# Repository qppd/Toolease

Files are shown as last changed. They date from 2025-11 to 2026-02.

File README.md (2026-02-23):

# ToolEase

**A modern, open-source RFID-based tool leasing and inventory management system for educational, industrial, and makerspace environments.**

---

## Table of Contents

- [Overview](#overview)
- [Key Features](#key-features)
- [System Architecture](#system-architecture)
- [Hardware Requirements](#hardware-requirements)
- [Wiring Diagram](#wiring-diagram)
- [Software Dependencies](#software-dependencies)
- [Installation & Setup](#installation--setup)
- [Configuration](#configuration)
- [Operation Guide](#operation-guide)
- [API & Communication](#api--communication)
- [Testing & Validation](#testing--validation)
- [Troubleshooting](#troubleshooting)
- [Project Structure](#project-structure)
- [Future Enhancements](#future-enhancements)
- [Contributing](#contributing)
- [Support & Contact](#support--contact)
- [License](#license)

---

## Overview

ToolEase is a complete IoT solution for managing tool lending, inventory, and asset tracking. It combines a robust Flutter mobile app with an ESP32-based RFID hardware interface, enabling real-time, per-unit tracking of tools and equipment. Designed for schools, universities, workshops, and industrial settings, ToolEase streamlines the process of borrowing, returning, and maintaining tools, ensuring accountability and reducing loss.

**Why ToolEase?**
- Eliminate manual logbooks and spreadsheets
- Prevent tool loss and unauthorized borrowing
- Gain real-time visibility into inventory and usage
- Simplify reporting and compliance

---

## Key Features

- **Per-Unit RFID Tracking:** Every tool is uniquely tagged and tracked
- **Student & User Management:** Register, search, and manage borrowers
- **Multi-Storage Support:** Organize tools by location or cabinet
- **Borrow/Return Workflow:** Scan to borrow, scan to return, with condition assessment
- **Admin Dashboard:** Real-time stats, PDF reports, and analytics
- **Kiosk Mode:** Secure, tablet-optimized interface for public use
- **Offline Operation:** Local database ensures reliability without internet
- **Auto-Reconnect:** Robust WiFi/WebSocket connection with status feedback
- **Security:** Biometric/PIN admin access, audit logs, and session management

---

## System Architecture

```
┌───────────────┐    WebSocket    ┌───────────────┐
│  Flutter App  │◄──────────────►│    ESP32      │
│   (Tablet)    │                │  (RFID HW)    │
│               │                │               │
│ • UI/UX       │                │ • MFRC522     │
│ • SQLite DB   │                │ • WiFi AP     │
│ • WebSocket   │                │ • AsyncServer │
└───────────────┘                └───────────────┘
     │                                 │
     ▼                                 ▼
   Students, Admins                  RFID Tags
```

---

## Bill of Materials (BOM) & Procurement Sources

Below is a comprehensive list of all components required to build the ToolEase system, grouped by category. Each item includes recommended sources and price notes. For the latest prices, search the listed stores (Lazada, Makerlab Electronics, TechLife, or your local hardware store).

### 1. Electronics (Makerlab Electronics – Lazada or Direct Store)

| Item | Quantity | Source | Price (₱, est.) | Notes |
|---|---|---|---|---|
| ESP32 30-pin module (ESP32-DEVKIT V1) | 1 | Makerlab Electronics (Lazada) | ~₱350 | WiFi microcontroller board |
| RFID-RC522 module | 1 | Makerlab Electronics (Lazada) | ~₱120 | RFID reader (SPI) |
| RFID Tags | 15 | Makerlab Electronics (Lazada) | ~₱300 | MIFARE Classic 1K/4K, cards or keyfobs |
| 24 AWG hookup wires | 1 bundle | Makerlab Electronics (Lazada) | ~₱80 | For all connections |
| JST-XH 4-pin connectors | 1 pack | Makerlab Electronics (Lazada) | ~₱40 | For modular wiring |
| JST-XH 3-pin connectors | 1 pack | Makerlab Electronics (Lazada) | ~₱40 | For modular wiring |

### 2. Display

| Item | Quantity | Source | Price (₱, est.) | Notes |
|---|---|---|---|---|
| 8-inch tablet – TechLife Lite 8" (TLPADL03) | 1 | TechLife Store / Lazada | ~₱4,999 | Main user interface |

### 3. Power System

| Item | Quantity | Source | Price (₱, est.) | Notes |
|---|---|---|---|---|
| 220V to 5V 3A power supply | 1 | Makerlab Electronics (Lazada) | ~₱180 | For stable power |

### 4. Enclosure / Physical Build (Hardware Store)

| Item | Quantity | Source | Price (₱, est.) | Notes |
|---|---|---|---|---|
| 1/2-inch Nebraska plywood (full sheet) | 1 | Local hardware store | ₱980 | For enclosure/cabinet |
| Nails | 1 pack | Local hardware store | ₱20 | For assembly |
| Tek screws | 1 pack | Local hardware store | ₱30 | For mounting |

---

### Procurement Notes

- **All electronics** (ESP32, RFID module, tags, wires, JST-XH connectors, power supply) are best sourced from **Makerlab Electronics** via Lazada or their direct store for quality and support.
- **Display/tablet** is available from the official TechLife store or Lazada. Always check for the latest model and price.
- **Enclosure materials** (plywood, nails, screws) are available at any local hardware store. Prices may vary by region.

### Total Estimated Cost Breakdown

| Category | Subtotal (₱, est.) |
|---|---|
| Electronics | ₱930 |
| Display | ₱4,999 |
| Power System | ₱180 |
| Enclosure | ₱1,030 |
| **Total** | **₱7,139** |

*Prices are estimates as of December 2025. Always check Lazada, Makerlab, and TechLife for current pricing and availability.*

---

## Physical Assembly & Views

ToolEase is designed for robust, real-world deployment. Below are detailed renders and diagrams to guide you through the assembly, wiring, and enclosure design. Each view and diagram is provided to ensure clarity for both hardware assembly and troubleshooting.

### Full Device Views

#### Complete Assembly (All Angles)

<p align="center">
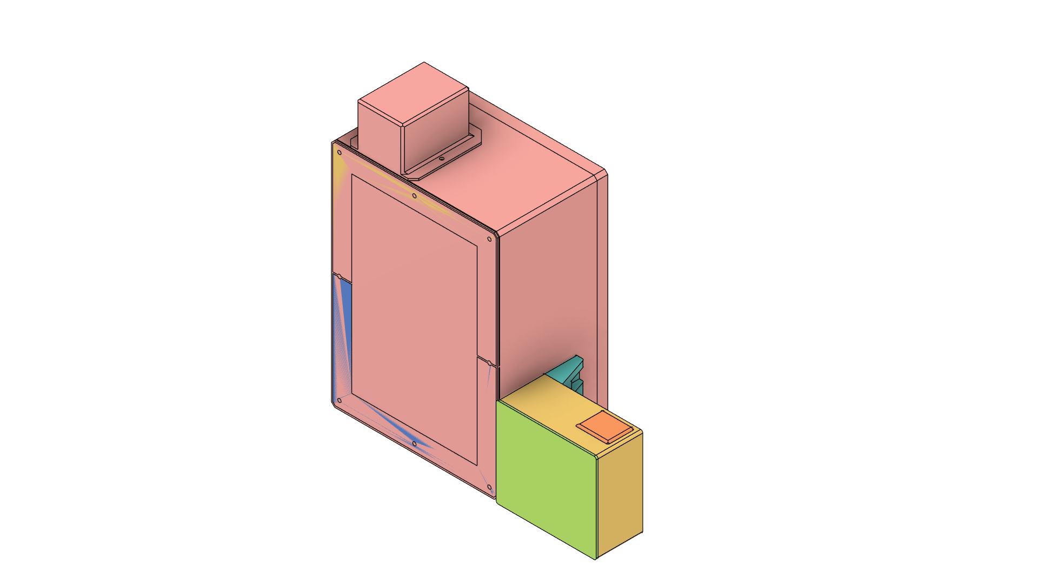
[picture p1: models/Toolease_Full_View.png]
Toolease Full View
  
</p>

This render shows the fully assembled ToolEase device, including the ESP32, RFID module, and all enclosure parts. Use this as a reference for the final look and for verifying that all components are properly housed.

#### Front View
<p align="center">
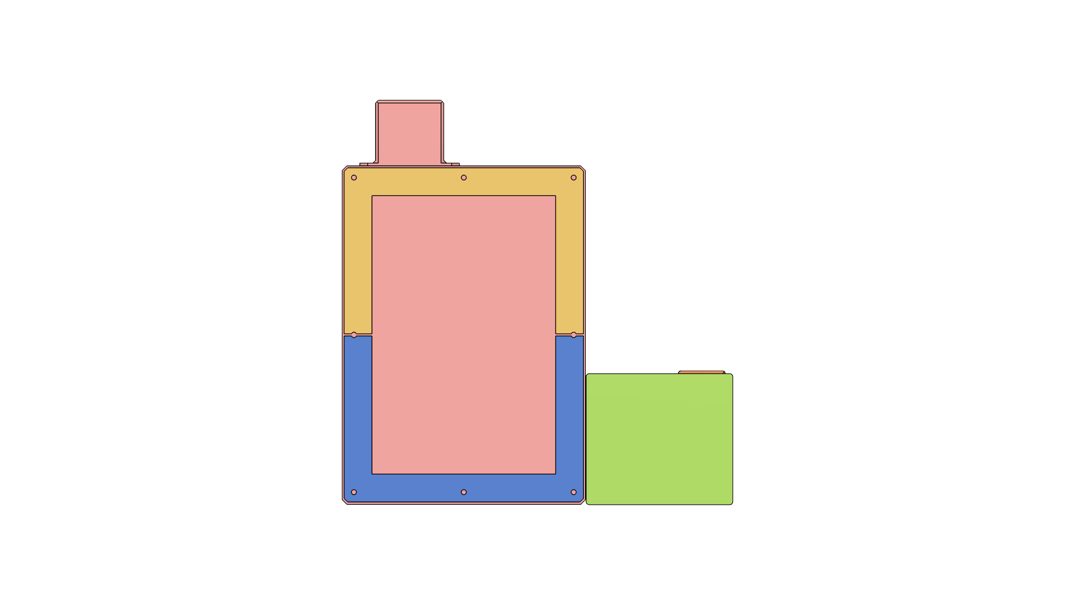
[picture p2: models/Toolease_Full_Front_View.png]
Toolease Front View
  
</p>
The front view highlights the RFID scan area, user interface, and any status indicators. This is the main interaction side for users.

#### Back View
<p align="center">
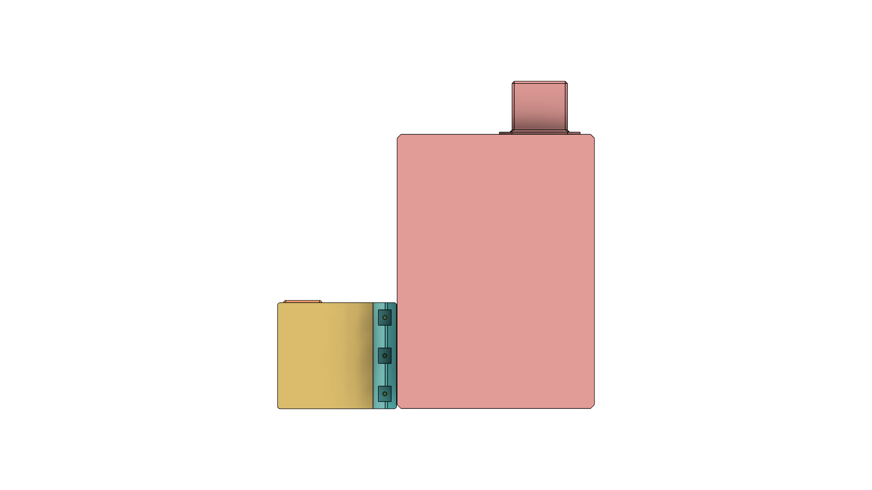
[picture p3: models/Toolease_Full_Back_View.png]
Toolease Back View
  
</p>
The back view shows cable management, mounting options, and access to the ESP32 board for maintenance.

#### Side View
<p align="center">
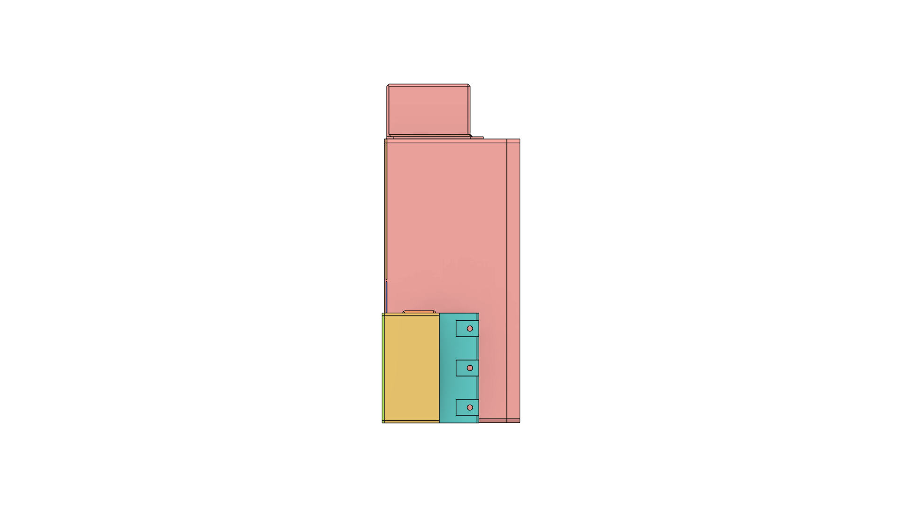
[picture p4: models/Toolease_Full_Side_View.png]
Toolease Side View
  
</p>
The side profile demonstrates the device’s thickness, bracket placement, and ventilation if present.

#### Top View
<p align="center">
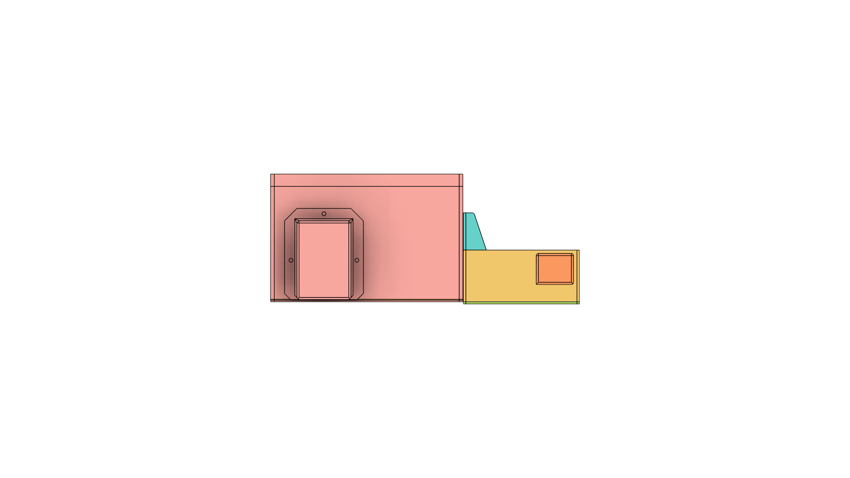
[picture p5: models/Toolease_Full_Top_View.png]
Toolease Top View
  
</p>
The top view is useful for understanding the layout of ports, buttons, and the RFID antenna’s position.

### 3D Printed Parts & Covers

**Download all STL files and 3D models on Thingiverse:**

<a href="https://www.thingiverse.com/thing:7220168" target="_blank">
  
</a>

All official ToolEase 3D printable parts are available for free on Thingiverse. Download, remix, or print the latest versions directly from the project page:
**[https://www.thingiverse.com/thing:7220168](https://www.thingiverse.com/thing:7220168)**

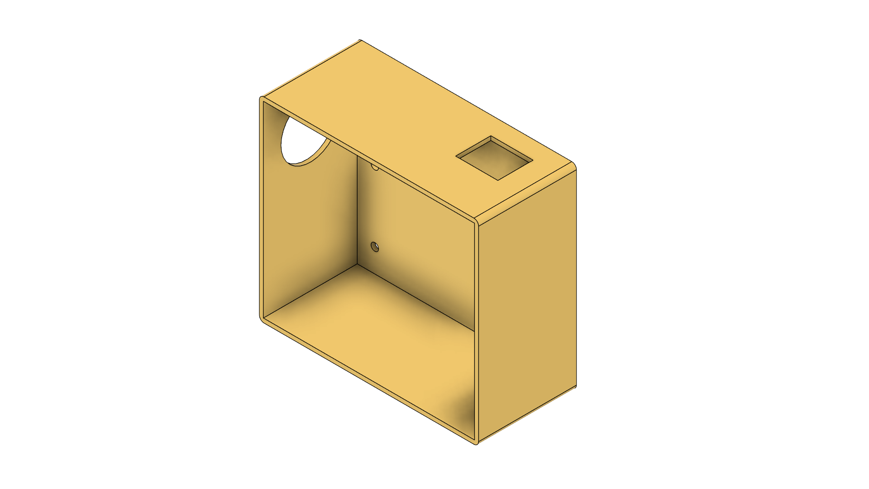
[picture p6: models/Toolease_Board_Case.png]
Board Case
- **Board Case:** 
  - Houses the ESP32 and main electronics, providing robust protection and easy access for maintenance.
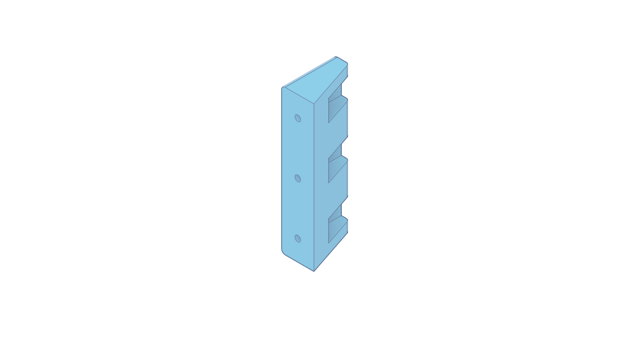
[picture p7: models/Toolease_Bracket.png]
Bracket
- **Bracket:** 
  - Used for mounting the device securely to a wall, table, or enclosure.
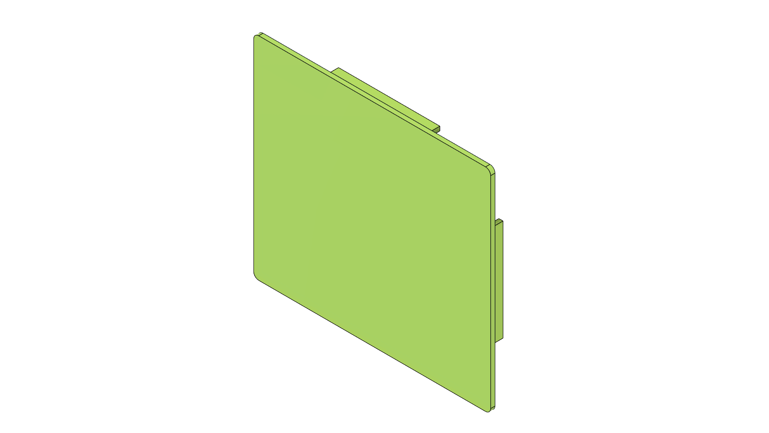
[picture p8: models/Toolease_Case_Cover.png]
Case Cover
- **Case Cover:** 
  - Protects the internal components and provides a clean, finished look.
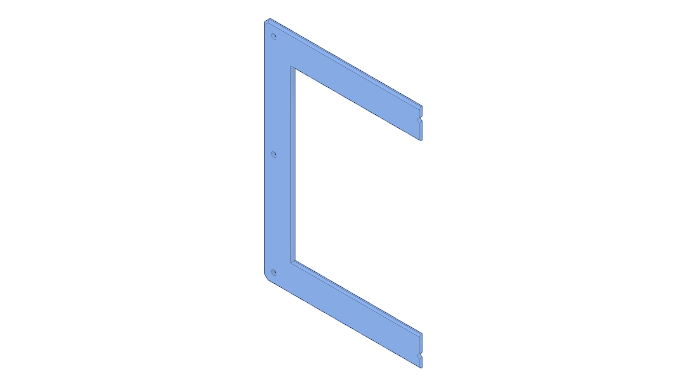
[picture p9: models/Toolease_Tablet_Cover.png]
Tablet Cover
- **Tablet Cover:** 
  - Custom-fit cover for the tablet, ensuring it stays in place and protected during use.
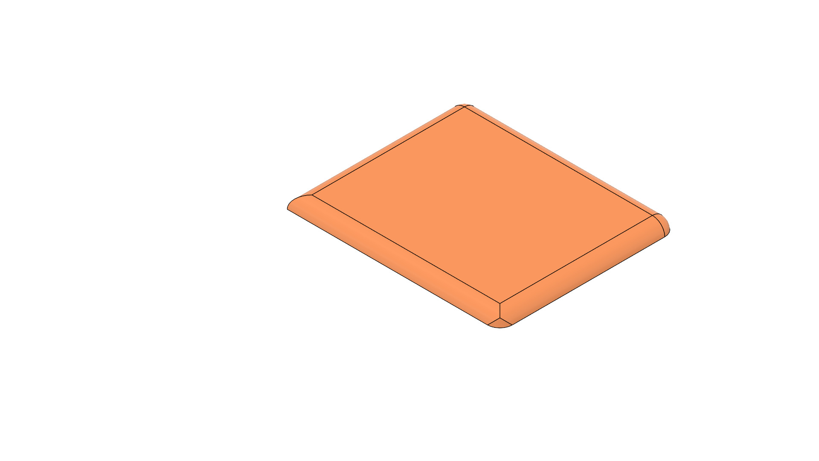
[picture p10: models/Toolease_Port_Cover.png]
Port Cover
- **Port Cover:** 
  - Shields the ESP32’s ports from dust and accidental contact.
- **Cable Cover:**
  - Cable Cover
  - A new addition designed to neatly route and protect power/data cables, preventing tangling and accidental unplugging. The cable cover snaps into place and can be removed for servicing.
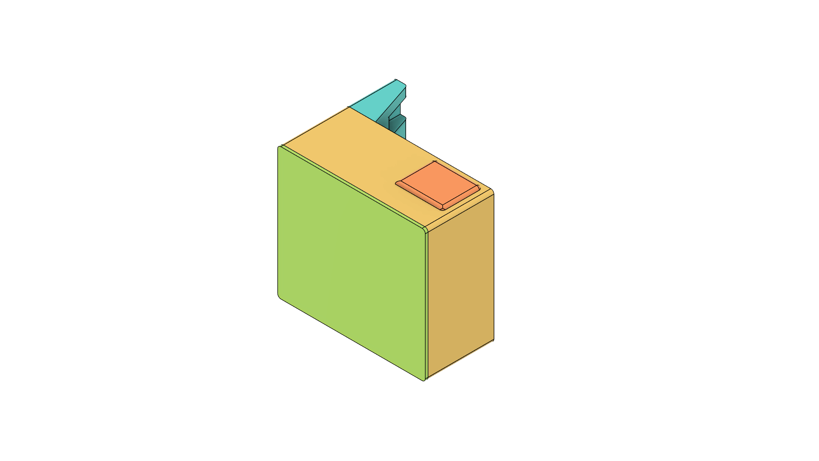
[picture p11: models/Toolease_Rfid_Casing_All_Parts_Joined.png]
All Parts
- **All Parts Joined:** 
  - Visual reference for how all 3D printed parts fit together in the final assembly.

Each part is designed for easy 3D printing and assembly. The covers, brackets, and cable management solutions ensure protection, stability, and a professional, safe finish for the device.

### Wiring Diagram & Fritzing

#### Visual Wiring Diagram
<p align="center">
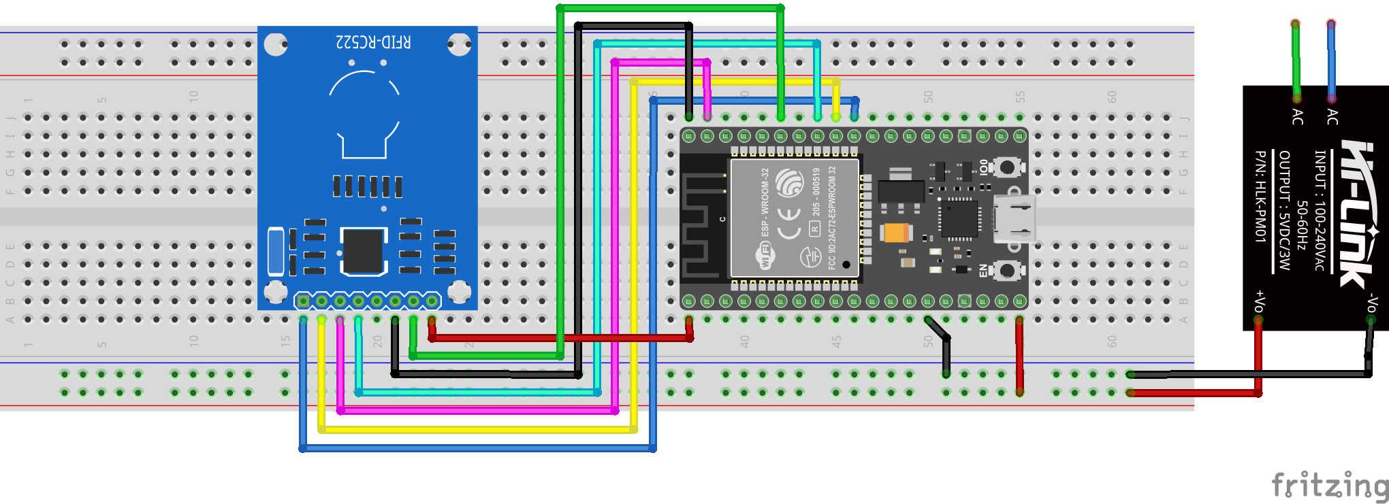
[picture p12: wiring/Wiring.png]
Wiring Diagram
  
</p>
This diagram provides a clear, color-coded map of all connections between the ESP32 and MFRC522 RFID module. Double-check your wiring against this image before powering on.

#### Fritzing Source File
- [Download Wiring.fzz](wiring/Wiring.fzz)

The Fritzing file allows you to view, edit, or print the wiring diagram using the Fritzing app. This is ideal for customizing the hardware layout or troubleshooting.

---

## Software Dependencies

### Flutter App
- Flutter SDK 3.8+
- Dart SDK 3.0+
- Riverpod, Drift ORM, Material 3, PDF, Kiosk Mode, Local Auth, Permission Handler

### ESP32 Firmware
- Arduino IDE 1.8+
- ESP32 Arduino Core v2.0.14
- ESPAsyncWebServer, AsyncTCP, EasyMFRC522

---

## Installation & Setup

### ESP32 Setup
1. Open Arduino IDE
2. Load `source/esp32/Toolease/Toolease.ino`
3. Select **ESP32 Dev Module** (Board Manager: v2.0.14 recommended)
4. Install libraries: ESPAsyncWebServer, AsyncTCP, EasyMFRC522
5. Upload firmware
6. Open Serial Monitor (115200 baud)
7. Confirm: "Access Point started" and "IP Address: 192.168.4.1"

### Flutter App Setup
1. Clone repository: `git clone https://github.com/qppd/Toolease.git`
2. `cd Toolease/source/flutter/Toolease`
3. Install dependencies: `flutter pub get`
4. Build and run: `flutter run` or `flutter build apk --release`
5. Install APK on tablet

### Connect Tablet to ESP32 WiFi
1. Settings → WiFi → Connect to `ToolEase_RFID` (password: `toolease123`)
2. Ignore "No internet" warning, turn OFF mobile data
3. Open ToolEase app, wait for green WiFi icon

---

## Configuration

### Flutter App
- Kiosk mode, feature toggles, biometric/PIN admin access, WebSocket server settings

### ESP32
- WiFi credentials, RFID pin assignments, WebSocket port (default 81), debug level

### Database
- Auto-migrates on first run; settings and admin credentials configurable in-app

---

## Operation Guide

### For Students
1. Register via app, enter details
2. Borrow: select item, scan RFID tag
3. Return: select item, scan RFID, assess condition

### For Admins
1. Authenticate, manage students/items/storages
2. Assign RFID tags, generate reports, configure settings

### RFID Workflow
1. Assign tag: admin selects item, places tag on reader, app writes data
2. Borrow: student scans tag, app records transaction
3. Return: scan tag, record condition

---

## API & Communication

### WebSocket Protocol
- **ESP32 → App:** `{ "action": "rfid_scan", "uid": "A1:B2:C3:D4:E5:F6" }`
- **App → ESP32:** `{ "action": "write_tag", "data": "item_id:unit_id" }`

### Database API
- Full CRUD for all entities, atomic transactions, real-time queries, advanced search/filter

### Serial Commands (ESP32)
- `test`, `scan <uid>`, `help`

---

## Testing & Validation

- Follow Quick Start and WiFi Setup
- Upload ESP32 firmware, verify AP
- Build/install app, connect to WiFi
- Test RFID scan, borrow/return, admin dashboard
- Simulate disconnects, test auto-reconnect
- Use Serial Monitor and Flutter DevTools for debugging

---

## Troubleshooting

| Issue | Solution |
|---|---|
| No WiFi network | ESP32 powered on? Serial Monitor shows AP? |
| Can't connect WiFi | Correct password? Mobile data OFF? |
| Red WiFi icon | Wait 3s for auto-reconnect. Check Serial Monitor. |
| Scan timeout | Green WiFi icon? Hold tag close to reader? |
| Connection drops | Move closer to ESP32. Check for interference. |

See full section above for detailed troubleshooting.

---

## Project Structure

```
Toolease/
├── LICENSE
├── README.md
├── models/           # 3D printable parts
├── source/
│   ├── esp32/
│   │   └── Toolease/ (firmware)
│   └── flutter/
│       └── Toolease/ (Flutter app)
└── wiring/           # Hardware diagrams
```

---

## Future Enhancements

- Cloud sync for multi-device
- Barcode/QR code support
- Advanced analytics and reporting
- Maintenance scheduling
- Mobile app for students
- Multi-location, centralized management
- AI-powered predictive maintenance

---

## Contributing

We welcome contributions! Please fork, create a feature branch, commit, and open a pull request. See code standards and dev setup in the repo.

---

## Support & Contact

- **Developer:** Quezon Province Provincial Developer
- **Email:** quezon.province.pd@gmail.com
- **Portfolio:** [sajed-mendoza.onrender.com](https://sajed-mendoza.onrender.com)
- **GitHub:** [qppd](https://github.com/qppd)
- **Facebook:** [qppd.dev](https://facebook.com/qppd.dev)

---

## License

MIT License. See [LICENSE](LICENSE) for details.

## 🚀 Quick Start

### ESP32 Setup
1. Open Arduino IDE
2. Load `source/esp32/Toolease/Toolease.ino`
3. Select **ESP32 Dev Module** (Board Manager: v2.0.14 recommended)
4. Install libraries: **ESPAsyncWebServer**, **AsyncTCP**, **EasyMFRC522**
5. Upload firmware
6. Open Serial Monitor (115200 baud)
7. You should see:
   - `Access Point started`
   - `IP Address: 192.168.4.1`
   - `WebSocket server started on port 80 at /ws`

### Tablet Setup
1. Connect to WiFi: `ToolEase_RFID` (password: `toolease123`)
2. Ignore "No internet" warning
3. Turn OFF mobile data
4. Open ToolEase app
5. Wait for **green WiFi icon**

### Usage
- **Green WiFi icon** = Connected
- **Red WiFi-off icon** = Not connected
- **RFID scanning** = Hold tag near RC522 for 1-2 seconds

### WiFi/WebSocket Details
```
SSID: ToolEase_RFID
Password: toolease123
IP: 192.168.4.1
WebSocket URL: ws://192.168.4.1/ws
```

---

## WiFi & WebSocket Setup

- ESP32 creates a WiFi Access Point (`ToolEase_RFID`)
- Tablet connects to ESP32 WiFi
- Communication is via WebSocket (`ws://192.168.4.1/ws`)
- No Bluetooth required
- Auto-reconnect and error handling built-in

**Troubleshooting:**
| Problem | Solution |
|---|---|
| No WiFi network | Restart ESP32, check Serial Monitor |
| Can't connect | Double-check password, turn off mobile data |
| Red WiFi icon | Wait 3 seconds for auto-reconnect |
| Scan timeout | Ensure green WiFi icon before scanning |
| Still not working? | Re-upload firmware, check library versions |

---

## System Features

- **Per-Unit RFID Tracking**: Every tool has a unique RFID tag (Serial No.)
- **Student Registration & Management**: Register students with ID, name, year, section
- **Storage Organization**: Manage multiple storage locations
- **Item Inventory**: Add/edit tools, assign RFID, track status (available, borrowed, lost, damaged)
- **Borrow/Return Workflow**: Scan to borrow, scan to return, condition tracking
- **Admin Panel**: Secure PIN/biometric access, real-time stats, PDF reports
- **Kiosk Mode**: Tablet-optimized, restricted navigation
- **Auto-Reconnect**: WiFi/WebSocket auto-reconnect for reliability

---

## Database & Code Structure

### Database
- **SQLite with Drift ORM**
- Per-unit item tracking (no more quantity fields)
- Borrow/return records linked to unique Serial No.

### Code Structure
- `lib/` (Flutter app)
   - `core/`, `database/`, `models/`, `providers/`, `screens/`, `services/`, `shared/`, `utils/`
- `source/esp32/Toolease/` (ESP32 firmware)
   - `Toolease.ino`, `Websocket_Config.cpp/.h`, `Rfid_Config.cpp/.h`

### ESP32 Pinout
```
ESP32       RC522
GPIO 5   -> SDA (SS)
GPIO 18  -> SCK
GPIO 23  -> MOSI
GPIO 19  -> MISO
GPIO 21  -> RST
3.3V     -> 3.3V
GND      -> GND
```

---

## Deployment & Testing

### Pre-Deployment Checklist
- [ ] ESP32 firmware uploaded, Serial Monitor shows correct logs
- [ ] Tablet connects to `ToolEase_RFID`, mobile data OFF
- [ ] ToolEase app installed, green WiFi icon appears
- [ ] RFID scan works for borrow/return
- [ ] Admin panel accessible, reports generate

### Build & Install
- `flutter pub get`
- `flutter run` or `flutter build apk --release`
- Install APK on tablet

### Testing
- Borrow/return workflow
- Student registration
- Admin dashboard
- Error handling (disconnect WiFi, scan timeout)

---

## Troubleshooting

**Common Issues:**
- ESP32 not creating WiFi: Check power, re-upload firmware
- Tablet won’t connect: Double-check password, mobile data OFF
- App not connecting: Confirm WebSocket URL is `ws://192.168.4.1/ws`
- Scan timeout: Ensure green WiFi icon, hold tag for 1-2 seconds
- Still stuck? Downgrade ESP32 core to 2.0.14, reinstall libraries

**Debug Tools:**
- Serial Monitor (ESP32)
- Flutter DevTools
- Network tools (ping, WebSocket test apps)

---

## Migration & Changelog

- Bluetooth code and dependencies **fully removed**
- ESP32 now uses **ESPAsyncWebServer** + **AsyncTCP** for WebSocket
- WebSocket URL changed to `ws://192.168.4.1/ws` (port 80)
- All Flutter code uses WebSocket only
- Per-unit RFID tracking, no more quantity fields
- All documentation merged into this README

---

## License

MIT License. See [LICENSE](LICENSE) for details.
- **Borrowing System**: Multi-storage, multi-item borrowing with real-time availability checking
- **Return Processing**: Condition-based return tracking (good, damaged, lost) for each item unit
- **Real-time Synchronization**: WebSocket-based communication between mobile app and RFID hardware

### Administrative Features
- **Admin Dashboard**: Real-time statistics and system overview
- **User Management**: Student registration and profile management
- **Inventory Control**: Comprehensive item and storage management
- **Transaction Records**: Complete borrowing history with archiving capabilities
- **Reporting System**: Generate PDF reports for inventory status and usage analytics
- **System Settings**: Configurable feature toggles and kiosk mode

### Hardware Integration
- **RFID Reading/Writing**: MFRC522-based tag detection and data storage
- **WiFi Connectivity**: Access Point and Station modes for flexible networking
- **WebSocket Server**: Real-time bidirectional communication
- **Serial Debugging**: Command-line interface for testing and diagnostics

### User Experience
- **Kiosk Mode**: Lockdown interface for public use scenarios
- **Biometric Authentication**: Local authentication for admin access
- **Responsive Design**: Optimized for tablets and mobile devices
- **Offline Operation**: Local database ensures functionality without internet
- **User Manuals**: Built-in help system for students and administrators

---

## System Architecture

```
┌─────────────────┐    WebSocket    ┌─────────────────┐
│   Flutter App   │◄──────────────►│     ESP32       │
│   (Mobile)      │                │  (Hardware)     │
│                 │                │                 │
│ • Student UI    │                │ • RFID Reader   │
│ • Admin UI      │                │ • MFRC522       │
│ • Database      │                │ • WiFi AP       │
│ • WebSocket     │                │ • WebSocket     │
│   Client        │                │   Server        │
└─────────────────┘                └─────────────────┘
         │                                 │
         │                                 │
         ▼                                 ▼
┌─────────────────┐               ┌─────────────────┐
│   SQLite DB     │               │   RFID Tags     │
│   (Drift ORM)   │               │   (MIFARE)      │
│                 │               │                 │
│ • Students      │               │ • UID Reading   │
│ • Items         │               │ • Data Storage  │
│ • BorrowRecords │               │ • Tag Writing  │
│ • Settings      │               │                 │
└─────────────────┘               └─────────────────┘
```

### Data Flow
1. **Registration**: Students register via mobile app → Stored in local SQLite
2. **Item Setup**: Admin adds items and assigns RFID tags → ESP32 writes tag data
3. **Borrowing**: Student selects items → App checks availability → RFID scan confirms
4. **Tracking**: ESP32 detects RFID tags → Broadcasts UID → App processes transaction
5. **Returns**: Student returns items → Condition assessment → Database update

---

## Hardware Components

### ESP32 Development Board
- **Microcontroller**: ESP32-WROOM-32
- **WiFi**: 802.11 b/g/n (2.4GHz)
- **GPIO Pins**: 36 total (configurable)
- **Power**: 5V USB or 3.3V regulated

### RFID Module (MFRC522)
- **Protocol**: MIFARE Classic 1K/4K, NTAG, etc.
- **Frequency**: 13.56 MHz
- **Communication**: SPI interface
- **Range**: Up to 10cm (depending on antenna)
- **Data Storage**: 1KB per tag (MIFARE Classic 1K)

### Power Supply
- **Input**: 5V USB or battery pack
- **Current**: 500mA minimum
- **Backup**: Optional battery for portability

---

## Software Components

### Flutter Application
- **Framework**: Flutter 3.8.1+
- **State Management**: Riverpod 2.6.1
- **Database**: Drift ORM 2.28.1
- **UI Components**: Material Design 3
- **Platform Support**: Android, iOS, Windows

### ESP32 Firmware
- **IDE**: Arduino IDE 1.8.0+
- **Core**: ESP32 Arduino Core
- **Libraries**:
   - EasyMFRC522 (RFID handling)
   - ArduinoWebsockets (WebSocket communication)
   - WiFi (networking)

### Key Dependencies
```yaml
# Flutter Dependencies
drift: ^2.28.1
flutter_riverpod: ^2.6.1
kiosk_mode: ^0.7.0
local_auth: ^2.3.0
pdf: ^3.11.1
permission_handler: ^12.0.1
```

---

## Database Schema

### Core Tables

#### Students
```sql
CREATE TABLE students (
  id INTEGER PRIMARY KEY AUTOINCREMENT,
  student_id TEXT UNIQUE NOT NULL,
  name TEXT NOT NULL,
  year_level TEXT NOT NULL,
  section TEXT NOT NULL,
  created_at DATETIME DEFAULT CURRENT_TIMESTAMP
);
```

#### Storages
```sql
CREATE TABLE storages (
  id INTEGER PRIMARY KEY AUTOINCREMENT,
  name TEXT NOT NULL,
  description TEXT,
  created_at DATETIME DEFAULT CURRENT_TIMESTAMP
);
```

#### Items
```sql
CREATE TABLE items (
  id INTEGER PRIMARY KEY AUTOINCREMENT,
  name TEXT NOT NULL,
  description TEXT,
  storage_id INTEGER REFERENCES storages(id),
  total_quantity INTEGER DEFAULT 0,
  available_quantity INTEGER DEFAULT 0,
  created_at DATETIME DEFAULT CURRENT_TIMESTAMP
);
```

#### ItemUnits
```sql
CREATE TABLE item_units (
  id INTEGER PRIMARY KEY AUTOINCREMENT,
  item_id INTEGER REFERENCES items(id),
  serial_no TEXT NOT NULL,
  status TEXT NOT NULL,
  created_at DATETIME DEFAULT CURRENT_TIMESTAMP
);
```

#### BorrowRecords
```sql
CREATE TABLE borrow_records (
  id INTEGER PRIMARY KEY AUTOINCREMENT,
  borrow_id TEXT UNIQUE NOT NULL,
  student_id INTEGER REFERENCES students(id),
  status TEXT NOT NULL,
  borrowed_at DATETIME DEFAULT CURRENT_TIMESTAMP,
  returned_at DATETIME
);
```

#### BorrowItems & Conditions
```sql
CREATE TABLE borrow_items (
  id INTEGER PRIMARY KEY AUTOINCREMENT,
  borrow_record_id INTEGER REFERENCES borrow_records(id),
  item_id INTEGER REFERENCES items(id),
  quantity INTEGER NOT NULL,
  return_condition TEXT
);

CREATE TABLE borrow_item_conditions (
  id INTEGER PRIMARY KEY AUTOINCREMENT,
  borrow_item_id INTEGER REFERENCES borrow_items(id),
  quantity_unit INTEGER NOT NULL,
  condition TEXT NOT NULL
);
```

### Supporting Tables
- **Settings**: App configuration and feature toggles
- **Tags**: Item categorization system

---

## Installation & Setup

## Installation & Setup (WiFi)

### Prerequisites
- **Flutter SDK**: 3.8.1 or higher
- **Dart SDK**: 3.0.0 or higher
- **Android Studio/VS Code**: With Flutter extensions
- **Arduino IDE**: 1.8.0+ with ESP32 support
- **Git**: Version control system

### ESP32 Setup
1. **Configure WiFi Credentials**
   - Open `source/esp32/Toolease/Toolease.ino` and set:
     ```cpp
     const char* ssid = "ToolEase_RFID";
     const char* password = "toolease123";
     ```
2. **Upload Firmware**
   - Open Arduino IDE
   - Connect ESP32 via USB
   - Select: Tools > Board > ESP32 Dev Module
   - Select correct Port
   - Click Upload
   - Open Serial Monitor (115200 baud)
   - Confirm: "Access Point started" and "IP Address: 192.168.4.1"

### Flutter App Setup
1. **Clone Repository**
   ```bash
   git clone https://github.com/qppd/Toolease.git
   cd Toolease/source/flutter/Toolease
   ```
2. **Install Dependencies**
   ```bash
   flutter pub get
   ```
3. **Build and Run**
   ```bash
   flutter run
   ```

### Connect Tablet to ESP32 WiFi
1. Go to Settings > WiFi
2. Connect to: ToolEase_RFID (password: toolease123)
3. Ignore "No internet" warning
4. Make sure Mobile Data is OFF

### Test RFID Scanning
1. Open ToolEase app
2. Wait for green WiFi icon
3. Try borrowing or registering a student and scan an RFID tag

---

### Hardware Assembly

1. **Connect MFRC522 to ESP32**:
   ```
   MFRC522    ESP32
   SDA(SS) -> GPIO5
   SCK      -> GPIO18
   MOSI     -> GPIO23
   MISO     -> GPIO19
   RST      -> GPIO21
   3.3V     -> 3.3V
   GND      -> GND
   ```

2. **Power Supply**: Connect USB or regulated power
3. **Antenna**: Ensure MFRC522 antenna is clear of obstructions

---

## Configuration

### Flutter App Settings
- **Kiosk Mode**: Enable/disable lockdown interface
- **Feature Toggles**: Control availability of registration, borrowing, returns
- **Authentication**: Configure biometric requirements
- **Network Settings**: WebSocket server configuration

### ESP32 Configuration
- **WiFi Credentials**: SSID and password for Access Point
- **RFID Pins**: GPIO assignments for MFRC522
- **WebSocket Port**: Default 81
- **Debug Level**: Serial output verbosity

### Database Initialization
The app automatically creates and migrates the database on first run. Default settings include:
- Kiosk mode disabled
- All features enabled
- Default admin credentials (if applicable)

---

## Operation Guide

## Operation Guide (WiFi)

### For Students
1. **Registration**: Register via app, enter details, submit.
2. **Borrowing**: Select items, scan RFID tag, confirm.
3. **Returning**: Select borrowed items, scan RFID tag, assess condition, confirm.

### For Administrators
1. **Admin Panel**: Authenticate, manage students/items/storages, assign tags, generate reports, configure settings.

### RFID Workflow
1. **Tag Assignment**: Admin selects item, places RFID tag near reader, app writes data.
2. **Borrowing**: Student selects items, scans RFID tag, transaction recorded.
3. **Returns**: Student returns items, RFID scan verifies, condition recorded.

### WiFi/WebSocket Connection
- ESP32 creates WiFi AP: ToolEase_RFID (password: toolease123)
- Tablet connects to WiFi
- App connects to ESP32 via WebSocket (port 81)
- Green WiFi icon = connected; red = not connected

---

## API & Communication

### WebSocket Protocol

#### ESP32 → Flutter Messages
```json
{
  "action": "rfid_scan",
  "uid": "A1:B2:C3:D4:E5:F6"
}
```

#### Flutter → ESP32 Messages
```json
{
  "action": "write_tag",
  "data": "item_id:unit_id"
}
```

### Database API

#### Key Operations
- **CRUD Operations**: Full Create, Read, Update, Delete for all entities
- **Transaction Management**: Atomic borrowing/return operations
- **Real-time Queries**: Live data updates via Riverpod providers
- **Search & Filtering**: Advanced querying capabilities

### Serial Commands (ESP32)

```
test          - Send test RFID scan
scan <uid>    - Send specific UID scan
help          - Display available commands
```

---

## Features in Detail

### Student Management
- **Registration**: Unique student ID validation
- **Profile Management**: Update student information
- **Borrowing History**: Track all transactions per student
- **Access Control**: Student ID verification for transactions

### Inventory Management
- **Multi-level Organization**: Storages → Items → Units
- **Quantity Tracking**: Total vs available quantities
- **RFID Integration**: Tag assignment and validation
- **Status Monitoring**: Track item conditions and availability

### Borrowing System
- **Multi-storage Selection**: Borrow from multiple locations
- **Quantity Selection**: Specify quantities per item
- **Real-time Validation**: Check availability before confirmation
- **Transaction IDs**: Unique borrow identifiers
- **Due Date Tracking**: Optional due date management

### Return Processing
- **Condition Assessment**: Good/Damaged/Lost per unit
- **Bulk Returns**: Process multiple items simultaneously
- **Damage Reporting**: Detailed condition tracking
- **Late Fee Calculation**: Optional penalty system

### RFID Integration
- **Tag Reading**: Automatic UID detection and broadcasting
- **Data Writing**: Store item/unit information on tags
- **Validation**: Verify tag data matches expected items
- **Error Handling**: Graceful handling of read/write failures

### Reporting & Analytics
- **Inventory Reports**: Current stock levels and locations
- **Usage Reports**: Borrowing patterns and frequency
- **Student Reports**: Individual borrowing history
- **System Reports**: Overall system utilization
- **PDF Export**: Professional report generation

### Security & Access Control
- **Biometric Authentication**: Fingerprint/Face ID for admin access
- **Kiosk Mode**: Prevent unauthorized system access
- **Session Management**: Automatic logout on inactivity
- **Audit Trail**: Complete transaction logging

---

## Testing & Validation

### Pre-Deployment Checklist
- [ ] Read Quick Start and WiFi Setup sections
- [ ] Upload ESP32 firmware, verify "Access Point started"
- [ ] Build and install Flutter app, connect to WiFi
- [ ] Verify green WiFi icon in app
- [ ] Test RFID scanning (borrow, return, manage items)
- [ ] Walk around with tablet, verify connection stability
- [ ] Try disconnecting/reconnecting WiFi, app should auto-reconnect
- [ ] Test error handling (turn off ESP32, disconnect WiFi, scan timeout)
- [ ] Test with multiple tablets if needed
- [ ] Review documentation and troubleshooting

### Functional Testing
- [ ] Student registration and lookup
- [ ] Item creation and RFID assignment
- [ ] Borrowing workflow completion
- [ ] Return processing with conditions
- [ ] Report generation and export
- [ ] Admin dashboard functionality
- [ ] Settings configuration
- [ ] Kiosk mode operation

---

## Troubleshooting

## Troubleshooting (WiFi)

### ESP32 Not Creating WiFi Network
**Problem:** Can't find "ToolEase_RFID" network on tablet
**Solutions:**
- Check ESP32 is powered on and Serial Monitor shows "Access Point started"
- Try restarting the ESP32 (unplug and plug back in)
- Make sure WiFi credentials in code match (case-sensitive)
- Some ESP32 boards need external antenna for better WiFi range

### Tablet Won't Connect to WiFi
**Problem:** "Authentication error" or "Failed to connect"
**Solutions:**
- Double-check password is exactly: `toolease123`
- Forget the network and reconnect
- Restart tablet WiFi
- Move closer to ESP32 (within 5-10 meters)

### App Shows "Not Connected"
**Problem:** Red WiFi-off icon even though WiFi is connected
**Solutions:**
1. **Check IP address:** ESP32 should be at `192.168.4.1`
2. **Verify WebSocket port:** Should be port `81`
3. **Wait a few seconds:** Auto-reconnect may be in progress
4. **Check Serial Monitor:** Should show "[WS] Client connecting..." when app connects
5. **Restart app:** Force close and reopen ToolEase
6. **Check firewall:** Some tablets may block local connections

### RFID Scan Times Out
**Problem:** "No RFID tag detected" even after scanning
**Solutions:**
- Check WebSocket connection (green WiFi icon)
- Verify RFID tag is registered in system
- Hold tag closer to RC522 reader
- Check Serial Monitor for RFID scan messages
- Try scanning slowly (1-2 seconds hold time)

### Connection Keeps Dropping
**Problem:** WiFi icon changes from green to red frequently
**Solutions:**
- Move tablet closer to ESP32
- Disable tablet battery optimization for ToolEase app
- Turn off **Mobile Data** completely
- Check for WiFi interference (microwaves, other 2.4GHz devices)
- Use external antenna on ESP32 if available

### Common Issues - Quick Reference
| Issue | Check This |
|---|---|
| No WiFi network | ESP32 powered on? Serial Monitor shows "Access Point started"? |
| Can't connect WiFi | Correct password (toolease123)? Mobile data OFF? |
| Red WiFi icon | Wait 3 seconds for auto-reconnect. Check Serial Monitor. |
| Scan timeout | Green WiFi icon first? Hold tag close to reader? |
| Connection drops | Move closer to ESP32. Check for interference. |

### Debug Tools
- **Serial Monitor**: ESP32 debugging output
- **Flutter DevTools**: App performance analysis
- **Database Inspector**: View SQLite data
- **Network Tools**: WebSocket traffic monitoring
# Migration Summary (Bluetooth → WiFi)

## ✅ ToolEase: Bluetooth Removed - WiFi Restored

### Summary of Changes
- All Bluetooth code and dependencies removed from both ESP32 and Flutter
- WebSocket over WiFi is now the only communication method
- ESP32 creates a WiFi Access Point (ToolEase_RFID)
- Tablet connects to ESP32 WiFi and communicates via WebSocket (port 81)
- All screens, providers, and services updated to use WebSocket
- Documentation and troubleshooting updated for WiFi workflow

### Key Improvements
- Simpler setup (no Bluetooth pairing)
- Faster and more reliable connection
- Auto-reconnect on disconnect
- Clearer connection status in app
- Better range and performance

### How to Use
1. Upload ESP32 firmware
2. Connect tablet to ToolEase_RFID WiFi
3. Launch ToolEase app
4. Look for green WiFi icon
5. Scan RFID tags as usual

### For full details, see the sections above and the [WiFi Setup](#installation--setup) and [Testing & Validation](#testing--validation) checklists.

---

## Project Structure

```
Toolease/
├── LICENSE
├── README.md
├── models/                          # 3D printable parts
│   ├── *.png                        # Render images
│   └── *.gcode                      # Print files
├── source/
│   ├── esp32/
│   │   └── Toolease/
│   │       ├── Toolease.ino         # Main firmware
│   │       ├── Rfid_Config.h/.cpp   # RFID handling
│   │       └── Websocket_Config.h/.cpp # Network comms
│   └── flutter/
│       └── Toolease/
│           ├── lib/
│           │   ├── main.dart        # App entry point
│           │   ├── core/            # Design system
│           │   ├── models/          # Data models
│           │   ├── providers/       # State management
│           │   ├── database/        # Drift database
│           │   ├── services/        # Business logic
│           │   ├── screens/         # UI screens
│           │   └── shared/          # Reusable components
│           ├── test/                # Unit tests
│           ├── android/             # Android config
│           ├── ios/                 # iOS config
│           └── pubspec.yaml         # Dependencies
└── wiring/                          # Hardware diagrams
```

---

## Future Enhancements

### Short Term
- [ ] Cloud synchronization for multi-device support
- [ ] Barcode/QR code integration alongside RFID
- [ ] Advanced search and filtering capabilities
- [ ] Email/SMS notifications for due dates
- [ ] Bulk import/export functionality

### Medium Term
- [ ] User roles and permissions system
- [ ] Maintenance scheduling and tracking
- [ ] Cost tracking and budgeting features
- [ ] Mobile app for students (companion to kiosk)
- [ ] Advanced analytics and reporting

### Long Term
- [ ] Multi-location support with centralized management
- [ ] Integration with existing LMS systems
- [ ] AI-powered predictive maintenance
- [ ] AR-based item identification
- [ ] Blockchain-based transaction verification

---

## Contributing

We welcome contributions to Toolease! Please follow these guidelines:

1. **Fork** the repository
2. **Create** a feature branch (`git checkout -b feature/YourFeature`)
3. **Commit** changes (`git commit -m 'Add YourFeature'`)
4. **Push** to branch (`git push origin feature/YourFeature`)
5. **Open** a Pull Request

### Development Setup
```bash
# Clone and setup
git clone https://github.com/qppd/Toolease.git
cd Toolease/source/flutter/Toolease
flutter pub get
flutter pub run build_runner build

# Run tests
flutter test

# Code formatting
flutter format .
```

### Code Standards
- Follow Flutter/Dart best practices
- Use Riverpod for state management
- Implement proper error handling
- Add unit tests for new features
- Update documentation

---

## Support & Contact

### Developer Information
- **Developer**: Quezon Province Provincial Developer
- **Email**: quezon.province.pd@gmail.com
- **Portfolio**: [sajed-mendoza.onrender.com](https://sajed-mendoza.onrender.com)
- **GitHub**: [qppd](https://github.com/qppd)

### Community
- **Facebook**: [qppd.dev](https://facebook.com/qppd.dev)
- **Facebook Page**: [QUEZONPROVINCEDEVS](https://facebook.com/QUEZONPROVINCEDEVS)

### Documentation
- **User Manual**: Built into the Flutter app
- **API Docs**: Inline code documentation
- **Hardware Guide**: Wiring diagrams and assembly instructions

---

## License

This project is licensed under the MIT License - see the [LICENSE](LICENSE) file for details.

---

## Acknowledgments

- **ESP32 Community**: Excellent documentation and support
- **Flutter Team**: Outstanding cross-platform framework
- **Drift ORM**: Powerful Dart database solution
- **MFRC522 Contributors**: Reliable RFID implementation
- **Open Source Libraries**: WebSockets, Riverpod, and more

---

*Built with ❤️ for educational institutions and workshops worldwide*

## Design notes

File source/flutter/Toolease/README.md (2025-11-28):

# ToolEase

<div align="center">

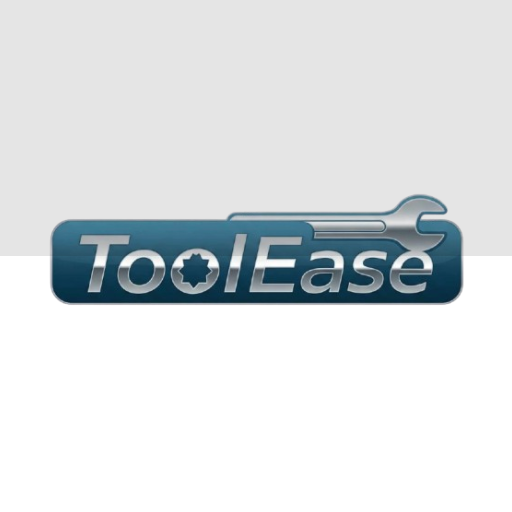
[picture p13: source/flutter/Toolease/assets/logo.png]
ToolEase Logo


**A Flutter-based inventory management kiosk application for Android tablets**

_Streamlining equipment borrowing and returning for educational institutions_





</div>

## 📖 Overview

ToolEase is a comprehensive inventory management system designed specifically for educational institutions. Built as a kiosk application for Android tablets, it provides a streamlined interface for students to borrow and return equipment while giving administrators powerful tools to manage inventory, track usage, and generate reports.

### Key Features

- **🎯 Dual Interface**: Student-facing kiosk mode and secure admin panel
- **📱 Kiosk-Ready**: Optimized for tablet deployment with restricted navigation
- **🔐 Secure Authentication**: Device PIN/biometric authentication for admin access
- **📊 Real-time Tracking**: Live inventory updates and comprehensive reporting

## 🚀 Quick Start

### Prerequisites

- **Flutter SDK**: 3.32.8 or higher
- **Dart SDK**: 3.8.1 or higher
- **Android Studio**: Latest version with Android SDK
- **Android Device**: API level 24+ (Android 7.0)

### Installation

1. **Clone the repository**

   ```bash
   git clone https://github.com/rvrdev/toolease.git
   cd toolease
   ```

2. **Install dependencies**

   ```bash
   flutter pub get
   ```

3. **Generate database code**

   ```bash
   flutter packages pub run build_runner build
   ```

4. **Run the application**
   ```bash
   flutter run
   ```

### Build for Production

```bash
# Build APK for release
flutter build apk --release

# Build App Bundle for Play Store
flutter build appbundle --release
```

## 🏗️ Architecture

ToolEase follows clean architecture principles with a clear separation of concerns:

```
lib/
├── core/              # Design system, themes, extensions
├── database/          # Drift ORM, tables, and generated code
├── models/            # Data models and business entities
├── providers/         # Riverpod state management
├── screens/           # UI screens and widgets
├── services/          # Business logic and external services
├── shared/            # Reusable widgets and utilities
└── utils/             # Helper functions and utilities
```

### Technology Stack

- **Frontend**: Flutter with Material Design 3
- **State Management**: Riverpod
- **Database**: Drift (SQLite)
- **Authentication**: local_auth package
- **Navigation**: MaterialApp with named routes
- **Reports**: PDF generation and file export

## 📱 Features

### Student Features (Public Access)

- **Self Registration**: Quick student profile creation
- **Item Borrowing**: Browse and borrow available equipment
- **Item Return**: Return borrowed items with condition tracking
- **User Manual**: Built-in help and usage instructions

### Admin Features (Authenticated Access)

- **Dashboard**: Real-time system overview and metrics
- **Inventory Management**: Full CRUD operations for items and storages
- **Student Management**: View and manage student records
- **Records Tracking**: Monitor active borrows and returns
- **Item Restoration**: Restore lost and damaged items back to available stock
  - Mark lost items as replaced
  - Mark damaged items as repaired
- **Advanced Reporting**: Generate PDF reports
- **System Settings**: Configure app behavior and features
- **User Manual**: Comprehensive admin documentation

### Core System Features

- **Kiosk Mode**: Secure tablet deployment with gesture-based admin access
- **Real-time Updates**: Live inventory tracking with quantity management and instant dashboard sync
- **Condition Tracking**: Individual item condition monitoring (Good/Damaged/Lost)
- **Item Restoration System**: Comprehensive lost/damaged item recovery with stock restoration
- **Data Export**: Comprehensive reporting and data export capabilities
- **Accessibility**: Full screen reader support and high contrast mode

## 🔧 Configuration

### Kiosk Mode Setup

1. Enable kiosk mode in admin settings
2. Deploy on Android tablet in kiosk mode
3. Use 5-tap gesture to access admin features
4. Configure permitted operations through settings panel

### Database Configuration

The application uses Drift (SQLite) for local data storage. Key tables include:

- `Students`: Student registration data
- `Items`: Inventory items with quantities
- `Storages`: Physical storage locations
- `BorrowRecords`: Transaction tracking
- `Settings`: App configuration

## 📊 Usage

### For Students

1. **Register**: Create student profile with ID, name, and class details
2. **Borrow**: Select items, specify quantities, receive borrow ID
3. **Return**: Enter student ID, mark item conditions, complete return

### For Administrators

1. **Access**: Authenticate using device PIN/biometric
2. **Manage**: Add/edit items, storages, and student records
3. **Monitor**: View dashboard metrics and active transactions
4. **Restore**: Recover lost and damaged items back to available stock
5. **Report**: Generate detailed usage and inventory reports

## 🧪 Testing

```bash
# Run all tests
flutter test

# Run tests with coverage
flutter test --coverage

# Analyze code quality
flutter analyze
```

## 🚀 Deployment

### Development Deployment

```bash
# Run in debug mode
flutter run --debug

# Run in profile mode for performance testing
flutter run --profile
```

### Production Deployment

```bash
# Build release APK
flutter build apk --release

# Install on device
flutter install --release
```

## 🤝 Contributing

We welcome contributions to ToolEase! Please follow these guidelines:

### Development Process

1. Fork the repository
2. Create a feature branch (`git checkout -b feature/amazing-feature`)
3. Write tests for new functionality
4. Commit changes (`git commit -m 'Add amazing feature'`)
5. Push to branch (`git push origin feature/amazing-feature`)
6. Open a Pull Request

### Code Standards

- Follow Dart/Flutter best practices
- Use the established design system
- Implement proper error handling
- Add documentation for complex logic
- Ensure accessibility compliance

## 📄 Documentation

- **[TODO.md](TODO.md)**: Project roadmap and task management
- **User Manuals**: Built into the application for both students and admins

## 🐛 Issues and Support

- **Bug Reports**: Use GitHub Issues with the `bug` label
- **Feature Requests**: Use GitHub Issues with the `enhancement` label
- **Questions**: Use GitHub Discussions for general questions

## 📜 License

This project is licensed under the MIT License - see the [LICENSE](LICENSE) file for details.

## 👥 Authors

- **Development Team** - _Initial work and ongoing maintenance_

## 🙏 Acknowledgments

- Flutter team for the excellent framework
- Drift team for the robust ORM solution
- Riverpod community for state management guidance
- Material Design team for design system inspiration

---

<div align="center">

**ToolEase** - _Simplifying inventory management for educational institutions_

</div>

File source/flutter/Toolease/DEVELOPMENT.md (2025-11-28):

# DEVELOPMENT.md

## ToolEase Inventory Management System - Development Documentation

**Project Name**: ToolEase
**Platform**: Android Tablet (Kiosk Application)
**Framework**: Flutter 3.x
**Language**: Dart
**Database**: SQLite with Drift ORM
**State Management**: Riverpod (Provider Pattern)
**Target Deployment**: Android tablets in kiosk mode

---

## Table of Contents

1. [System Overview](#system-overview)
2. [Development Architecture](#development-architecture)
3. [Database Design](#database-design)
4. [Development Process](#development-process)
5. [Feature Implementation](#feature-implementation)
6. [Build and Deployment](#build-and-deployment)
7. [Testing Strategy](#testing-strategy)
8. [Technical Specifications](#technical-specifications)

---

## 1. System Overview

### 1.1 Purpose

ToolEase is an inventory management kiosk application designed to streamline the borrowing and returning process of items for students in an educational or organizational setting. The system provides:

- **Public Access**: Students can register, borrow items, and return items
- **Admin Access**: Single administrator can manage inventory, view records, and configure system
- **Real-time Tracking**: Live inventory status with quantity management
- **Condition Monitoring**: Track item conditions (good, damaged, lost)

### 1.2 Key Requirements

- **Kiosk Mode Operation**: Run as a locked-down kiosk on Android tablets
- **Offline Capability**: Full functionality without internet connection
- **Single Admin Authentication**: Device PIN/password-based admin access
- **Real-time Updates**: Immediate UI updates across all screens
- **PDF Report Generation**: Export records and reports

---

## 2. Development Architecture

### 2.1 Clean Architecture Pattern

The application follows Clean Architecture principles with clear separation of concerns:

```
┌─────────────────────────────────────────┐
│         Presentation Layer              │
│    (UI Screens, Widgets, Providers)     │
└──────────────┬──────────────────────────┘
               │
┌──────────────▼──────────────────────────┐
│         Business Logic Layer            │
│    (Services, Use Cases, Validators)    │
└──────────────┬──────────────────────────┘
               │
┌──────────────▼──────────────────────────┐
│          Data Layer                     │
│   (Database, Models, Repositories)      │
└─────────────────────────────────────────┘
```

### 2.2 Directory Structure

```
lib/
├── core/                      # Design system and core utilities
│   ├── colors.dart           # Color palette
│   ├── spacing.dart          # Spacing constants
│   ├── theme.dart            # Material theme configuration
│   └── typography.dart       # Text styles
│
├── database/                 # Data persistence layer
│   ├── tables.dart          # Drift table definitions
│   ├── database.dart        # Database class
│   └── database.g.dart      # Generated database code
│
├── models/                   # Data models and DTOs
│   ├── student.dart
│   ├── item.dart
│   ├── borrow_record.dart
│   └── quantity_condition.dart
│
├── providers/                # State management
│   ├── database_provider.dart
│   ├── item_provider.dart
│   ├── student_provider.dart
│   └── settings_provider.dart
│
├── screens/                  # UI screens
│   ├── home/                # Home screen
│   ├── register/            # Student registration
│   ├── borrow/              # Borrowing workflow
│   ├── return/              # Return workflow
│   └── admin/               # Admin dashboard and management
│
├── services/                 # Business logic services
│   ├── database_service.dart
│   ├── auth_service.dart
│   ├── kiosk_service.dart
│   └── pdf_service.dart
│
├── shared/widgets/          # Reusable UI components
│   ├── app_card.dart
│   ├── action_card.dart
│   ├── custom_button.dart
│   └── loading_overlay.dart
│
└── utils/                   # Utility functions
    ├── validators.dart
    ├── formatters.dart
    └── constants.dart
```

### 2.3 State Management Architecture

**Riverpod Provider Pattern:**

```dart
// Provider hierarchy
┌─────────────────────────┐
│  DatabaseProvider       │  (Singleton)
└───────────┬─────────────┘
            │
     ┌──────┴──────┐
     ▼             ▼
┌─────────┐   ┌─────────┐
│ Student │   │  Item   │  (StreamProviders)
│Provider │   │Provider │
└─────────┘   └─────────┘
     │             │
     └──────┬──────┘
            ▼
    ┌───────────────┐
    │ BorrowRecord  │
    │   Provider    │
    └───────────────┘
```

---

## 3. Database Design

### 3.1 Entity-Relationship Diagram

```
┌─────────────┐
│  Students   │
└──────┬──────┘
       │
       │ 1:N
       │
┌──────▼──────────┐
│ BorrowRecords   │
└──────┬──────────┘
       │
       │ 1:N
       │
┌──────▼──────────┐      N:1    ┌──────────┐
│  BorrowItems    │◄─────────────┤  Items   │
└──────┬──────────┘              └────┬─────┘
       │                              │
       │ 1:N                       N:1│
       │                              │
┌──────▼──────────────┐         ┌────▼─────┐
│ BorrowItemConditions│         │ Storages │
└─────────────────────┘         └──────────┘
```

### 3.2 Database Tables

#### Students Table
```dart
class Students extends Table {
  IntColumn get id => integer().autoIncrement()();
  TextColumn get studentId => text().unique()();
  TextColumn get firstName => text()();
  TextColumn get lastName => text()();
  TextColumn get course => text()();
  IntColumn get yearLevel => integer()();
  TextColumn get section => text()();
  DateTimeColumn get createdAt => dateTime()();
}
```

#### Items Table
```dart
class Items extends Table {
  IntColumn get id => integer().autoIncrement()();
  TextColumn get name => text()();
  TextColumn get description => text().nullable()();
  IntColumn get totalQuantity => integer()();
  IntColumn get availableQuantity => integer()();
  IntColumn get storageId => integer().references(Storages, #id)();
  DateTimeColumn get createdAt => dateTime()();
  DateTimeColumn get updatedAt => dateTime()();
}
```

#### BorrowRecords Table
```dart
class BorrowRecords extends Table {
  IntColumn get id => integer().autoIncrement()();
  TextColumn get borrowId => text().unique()();
  IntColumn get studentId => integer().references(Students, #id)();
  DateTimeColumn get borrowDate => dateTime()();
  DateTimeColumn get dueDate => dateTime()();
  DateTimeColumn get returnDate => dateTime().nullable()();
  TextColumn get status => text()(); // 'borrowed', 'returned'
  DateTimeColumn get createdAt => dateTime()();
}
```

#### BorrowItems Table
```dart
class BorrowItems extends Table {
  IntColumn get id => integer().autoIncrement()();
  IntColumn get borrowRecordId => integer().references(BorrowRecords, #id)();
  IntColumn get itemId => integer().references(Items, #id)();
  IntColumn get quantityBorrowed => integer()();
  DateTimeColumn get createdAt => dateTime()();
}
```

#### BorrowItemConditions Table (Quantity Tracking)
```dart
class BorrowItemConditions extends Table {
  IntColumn get id => integer().autoIncrement()();
  IntColumn get borrowItemId => integer().references(BorrowItems, #id)();
  TextColumn get condition => text()(); // 'good', 'damaged', 'lost'
  DateTimeColumn get createdAt => dateTime()();
  DateTimeColumn get updatedAt => dateTime()();
}
```

### 3.3 Database Code Generation

The system uses Drift ORM for type-safe database operations:

```bash
# Generate database code
flutter packages pub run build_runner build --delete-conflicting-outputs
```

**Generated Files:**
- `lib/database/database.g.dart` - Database implementation
- Query methods, data access objects (DAOs)
- Type-safe SQL query builders

---

## 4. Development Process

### 4.1 Initial Setup and Planning

**Phase 1: Requirements Analysis**
- Identified core user workflows (register, borrow, return)
- Defined admin requirements (authentication, management)
- Determined kiosk mode constraints
- Established offline-first architecture

**Phase 2: Technology Selection**
- **Flutter**: Cross-platform framework with excellent UI capabilities
- **Drift**: Type-safe SQLite ORM for offline data persistence
- **Riverpod**: Modern provider pattern for state management
- **local_auth**: Biometric/PIN authentication for admin access

### 4.2 Development Workflow

```
1. Feature Planning
   ↓
2. Database Schema Design
   ↓
3. Model Creation
   ↓
4. Service Layer Implementation
   ↓
5. Provider Setup
   ↓
6. UI Screen Development
   ↓
7. Integration Testing
   ↓
8. User Acceptance Testing
```

### 4.3 Git Workflow

```bash
# Development branch strategy
master (production-ready code)
  ↓
feature/* (new features)
bugfix/* (bug fixes)
hotfix/* (urgent production fixes)
```

### 4.4 Code Generation Commands

```bash
# Install dependencies
flutter pub get

# Generate database code
flutter packages pub run build_runner build

# Clean and regenerate
flutter clean
flutter pub get
flutter packages pub run build_runner build --delete-conflicting-outputs

# Analyze code quality
flutter analyze

# Run tests
flutter test
```

---

## 5. Feature Implementation

### 5.1 Student Registration Flow

**Implementation Steps:**

1. **UI Design**: Create registration form with validation
2. **Service Method**: `DatabaseService.registerStudent()`
3. **Provider Integration**: StudentProvider with AsyncValue
4. **Error Handling**: Validate unique student ID, required fields

```dart
// Service Layer
Future<Student> registerStudent(StudentRegistrationData data) async {
  // Validate student ID uniqueness
  final existing = await (select(students)
    ..where((s) => s.studentId.equals(data.studentId)))
    .getSingleOrNull();

  if (existing != null) {
    throw Exception('Student ID already exists');
  }

  // Insert new student
  final studentId = await into(students).insert(
    StudentsCompanion.insert(
      studentId: data.studentId,
      firstName: data.firstName,
      lastName: data.lastName,
      course: data.course,
      yearLevel: data.yearLevel,
      section: data.section,
      createdAt: DateTime.now(),
    ),
  );

  return await getStudent(studentId);
}
```

### 5.2 Borrow Workflow Implementation

**Borrow ID Generation:**
```dart
// Format: 25XXXXX (year + sequential number)
Future<String> generateBorrowId() async {
  final year = DateTime.now().year % 100; // Last 2 digits
  final count = await (select(borrowRecords)).get().then((r) => r.length);
  final sequence = (count + 1).toString().padLeft(5, '0');
  return '$year$sequence'; // e.g., "2500001"
}
```

**Multi-Item Borrowing:**
1. Create BorrowRecord with generated borrowId
2. Insert multiple BorrowItems
3. Create individual QuantityConditions for each unit
4. Update item availableQuantity
5. Use database transaction for atomicity

```dart
Future<BorrowRecord> createBorrowRecord({
  required int studentId,
  required List<BorrowItemData> items,
  required DateTime dueDate,
}) async {
  return await transaction(() async {
    // 1. Create borrow record
    final borrowId = await generateBorrowId();
    final recordId = await into(borrowRecords).insert(
      BorrowRecordsCompanion.insert(
        borrowId: borrowId,
        studentId: studentId,
        borrowDate: DateTime.now(),
        dueDate: dueDate,
        status: 'borrowed',
        createdAt: DateTime.now(),
      ),
    );

    // 2. Create borrow items and conditions
    for (final itemData in items) {
      final borrowItemId = await into(borrowItems).insert(
        BorrowItemsCompanion.insert(
          borrowRecordId: recordId,
          itemId: itemData.itemId,
          quantityBorrowed: itemData.quantity,
          createdAt: DateTime.now(),
        ),
      );

      // 3. Create individual conditions for each unit
      for (int i = 0; i < itemData.quantity; i++) {
        await into(borrowItemConditions).insert(
          BorrowItemConditionsCompanion.insert(
            borrowItemId: borrowItemId,
            condition: 'good',
            createdAt: DateTime.now(),
            updatedAt: DateTime.now(),
          ),
        );
      }

      // 4. Update item quantity
      final item = await getItem(itemData.itemId);
      await (update(items)..where((i) => i.id.equals(itemData.itemId)))
        .write(ItemsCompanion(
          availableQuantity: Value(item.availableQuantity - itemData.quantity),
          updatedAt: Value(DateTime.now()),
        ));
    }

    return await getBorrowRecord(recordId);
  });
}
```

### 5.3 Return Workflow with Condition Tracking

**Per-Unit Condition Selection:**
- Student selects condition for each borrowed unit
- Conditions: Good, Damaged, Lost
- UI shows individual checkboxes for quantity tracking

```dart
Future<void> returnBorrowRecord({
  required int recordId,
  required Map<int, List<String>> itemConditions, // borrowItemId -> conditions
}) async {
  await transaction(() async {
    // 1. Update borrow record status
    await (update(borrowRecords)..where((r) => r.id.equals(recordId)))
      .write(BorrowRecordsCompanion(
        status: const Value('returned'),
        returnDate: Value(DateTime.now()),
      ));

    // 2. Update conditions and item quantities
    for (final entry in itemConditions.entries) {
      final borrowItemId = entry.key;
      final conditions = entry.value;

      // Get condition records
      final conditionRecords = await (select(borrowItemConditions)
        ..where((c) => c.borrowItemId.equals(borrowItemId)))
        .get();

      // Update each condition
      for (int i = 0; i < conditions.length; i++) {
        await (update(borrowItemConditions)
          ..where((c) => c.id.equals(conditionRecords[i].id)))
          .write(BorrowItemConditionsCompanion(
            condition: Value(conditions[i]),
            updatedAt: Value(DateTime.now()),
          ));
      }

      // 3. Update item quantities
      final borrowItem = await getBorrowItem(borrowItemId);
      final item = await getItem(borrowItem.itemId);

      final goodCount = conditions.where((c) => c == 'good').length;

      // Only good items restore available quantity
      await (update(items)..where((i) => i.id.equals(borrowItem.itemId)))
        .write(ItemsCompanion(
          availableQuantity: Value(item.availableQuantity + goodCount),
          updatedAt: Value(DateTime.now()),
        ));
    }
  });
}
```

### 5.4 Item Restoration Feature

**Lost/Damaged Item Recovery:**

```dart
// Restore lost items (marked as replaced)
Future<void> restoreLostItemsToStock(List<int> conditionIds) async {
  await transaction(() async {
    for (final conditionId in conditionIds) {
      // 1. Get condition and related item
      final condition = await getCondition(conditionId);
      final borrowItem = await getBorrowItem(condition.borrowItemId);
      final item = await getItem(borrowItem.itemId);

      // 2. Update condition to good
      await (update(borrowItemConditions)
        ..where((c) => c.id.equals(conditionId)))
        .write(BorrowItemConditionsCompanion(
          condition: const Value('good'),
          updatedAt: Value(DateTime.now()),
        ));

      // 3. Restore to available quantity (NOT total)
      await (update(items)..where((i) => i.id.equals(borrowItem.itemId)))
        .write(ItemsCompanion(
          availableQuantity: Value(item.availableQuantity + 1),
          updatedAt: Value(DateTime.now()),
        ));
    }
  });
}

// Restore damaged items (marked as repaired)
Future<void> restoreDamagedItemsToStock(List<int> conditionIds) async {
  // Same logic as restoreLostItemsToStock
  // Updates availableQuantity only, not totalQuantity
}
```

### 5.5 Admin Authentication

**Device PIN/Password Authentication:**

```dart
import 'package:local_auth/local_auth.dart';

class AuthService {
  final LocalAuthentication _auth = LocalAuthentication();

  Future<bool> authenticateAdmin() async {
    try {
      final canAuthenticate = await _auth.canCheckBiometrics ||
                             await _auth.isDeviceSupported();

      if (!canAuthenticate) {
        return false;
      }

      return await _auth.authenticate(
        localizedReason: 'Authenticate to access admin features',
        options: const AuthenticationOptions(
          useErrorDialogs: true,
          stickyAuth: true,
        ),
      );
    } catch (e) {
      return false;
    }
  }
}
```

### 5.6 Kiosk Mode Implementation

**Android Kiosk Service:**

```dart
class KioskService {
  static const platform = MethodChannel('com.toolease/kiosk');

  Future<void> enableKioskMode() async {
    try {
      await platform.invokeMethod('enableKioskMode');
    } catch (e) {
      print('Failed to enable kiosk mode: $e');
    }
  }

  Future<void> disableKioskMode() async {
    try {
      await platform.invokeMethod('disableKioskMode');
    } catch (e) {
      print('Failed to disable kiosk mode: $e');
    }
  }
}
```

**Android Native Code (MainActivity.kt):**

```kotlin
class MainActivity: FlutterActivity() {
    private val CHANNEL = "com.toolease/kiosk"

    override fun configureFlutterEngine(flutterEngine: FlutterEngine) {
        super.configureFlutterEngine(flutterEngine)

        MethodChannel(flutterEngine.dartExecutor.binaryMessenger, CHANNEL)
            .setMethodCallHandler { call, result ->
                when (call.method) {
                    "enableKioskMode" -> {
                        enableKioskMode()
                        result.success(null)
                    }
                    "disableKioskMode" -> {
                        disableKioskMode()
                        result.success(null)
                    }
                    else -> result.notImplemented()
                }
            }
    }

    private fun enableKioskMode() {
        window.decorView.systemUiVisibility = (
            View.SYSTEM_UI_FLAG_HIDE_NAVIGATION
            or View.SYSTEM_UI_FLAG_FULLSCREEN
            or View.SYSTEM_UI_FLAG_IMMERSIVE_STICKY
        )
    }
}
```

### 5.7 Real-time Provider Updates

**Provider Invalidation for Dashboard Updates:**

```dart
// After database operations, invalidate providers
await databaseService.restoreLostItemsToStock(selectedIds);

// Invalidate providers for real-time updates
ref.invalidate(itemsProvider);
ref.invalidate(borrowRecordsProvider);
ref.invalidate(dashboardStatsProvider);
```

---

## 6. Build and Deployment

### 6.1 Build Configuration

**android/app/build.gradle:**

```gradle
android {
    compileSdkVersion 34

    defaultConfig {
        applicationId "com.toolease.app"
        minSdkVersion 21
        targetSdkVersion 34
        versionCode 1
        versionName "1.0.0"
    }

    buildTypes {
        release {
            signingConfig signingConfigs.release
            minifyEnabled true
            shrinkResources true
        }
    }
}
```

### 6.2 Build Commands

```bash
# Development build
flutter run

# Release APK
flutter build apk --release

# App Bundle (for Play Store)
flutter build appbundle --release

# Split APKs by ABI
flutter build apk --split-per-abi --release
```

### 6.3 Release Preparation

1. **Update Version**: Increment version in `pubspec.yaml`
2. **Run Tests**: `flutter test`
3. **Code Analysis**: `flutter analyze`
4. **Build Release**: `flutter build apk --release`
5. **Test APK**: Install and test on physical device
6. **Sign APK**: Use Android signing keys
7. **Deploy**: Transfer to tablet devices

### 6.4 Kiosk Deployment Setup

**Device Configuration:**

1. Enable Developer Options
2. Enable USB Debugging
3. Install APK via ADB:
   ```bash
   adb install app-release.apk
   ```
4. Set ToolEase as launcher app
5. Configure device as single-app kiosk
6. Disable system navigation (if supported)

**MDM Configuration (Optional):**
- Deploy via Mobile Device Management
- Configure kiosk restrictions
- Set auto-start on boot
- Disable app uninstallation

---

## 7. Testing Strategy

### 7.1 Unit Tests

```dart
// Test database operations
test('Should register student with unique ID', () async {
  final service = DatabaseService();
  final student = await service.registerStudent(
    StudentRegistrationData(
      studentId: '2024-001',
      firstName: 'John',
      lastName: 'Doe',
      course: 'BSIT',
      yearLevel: 1,
      section: 'A',
    ),
  );

  expect(student.studentId, '2024-001');
});

// Test borrow ID generation
test('Should generate correct borrow ID format', () async {
  final service = DatabaseService();
  final borrowId = await service.generateBorrowId();
  expect(borrowId, matches(r'^\d{7}$')); // Format: YYXXXXX
});
```

### 7.2 Integration Tests

```dart
// Test complete borrow workflow
testWidgets('Should complete borrow workflow', (tester) async {
  await tester.pumpWidget(MyApp());

  // Navigate to borrow screen
  await tester.tap(find.text('Borrow Items'));
  await tester.pumpAndSettle();

  // Select student
  await tester.tap(find.text('Search Student'));
  await tester.enterText(find.byType(TextField), '2024-001');
  await tester.pump();

  // Select items
  await tester.tap(find.text('Add Item'));
  // ... complete workflow

  // Verify success
  expect(find.text('Borrowed Successfully'), findsOneWidget);
});
```

### 7.3 Manual Testing Checklist

- [ ] Student registration with duplicate ID prevention
- [ ] Item borrowing with quantity updates
- [ ] Return workflow with condition tracking
- [ ] Lost/damaged item restoration
- [ ] Admin authentication
- [ ] Kiosk mode activation/deactivation
- [ ] PDF report generation
- [ ] Dashboard real-time updates
- [ ] Settings persistence
- [ ] Offline functionality

---

## 8. Technical Specifications

### 8.1 Dependencies

```yaml
dependencies:
  flutter:
    sdk: flutter

  # State Management
  flutter_riverpod: ^2.4.9

  # Database
  drift: ^2.14.0
  sqlite3_flutter_libs: ^0.5.18
  path_provider: ^2.1.1
  path: ^1.8.3

  # Authentication
  local_auth: ^2.1.7

  # UI Components
  intl: ^0.18.1

  # PDF Generation
  pdf: ^3.10.7
  printing: ^5.11.1

dev_dependencies:
  flutter_test:
    sdk: flutter
  build_runner: ^2.4.6
  drift_dev: ^2.14.0
```

### 8.2 Performance Optimizations

- **Database Indexing**: Indexes on frequently queried columns
- **Lazy Loading**: Load data on demand, not upfront
- **Provider Caching**: Cache provider results when appropriate
- **Image Optimization**: Compress and cache images
- **Code Splitting**: Lazy load admin screens

### 8.3 Security Measures

- **SQL Injection Prevention**: Use parameterized queries (Drift handles this)
- **Input Validation**: Validate all user inputs
- **Authentication**: Device-level PIN/biometric for admin
- **Data Privacy**: No sensitive data logging
- **Secure Storage**: SQLite database with proper permissions

### 8.4 System Requirements

**Development Environment:**
- Flutter SDK 3.16.0 or higher
- Dart SDK 3.2.0 or higher
- Android Studio / VS Code
- Android SDK (API 21-34)

**Target Device:**
- Android 5.0 (API 21) or higher
- Minimum 2GB RAM
- 100MB storage space
- Touch screen support

### 8.5 Known Limitations

- **Single Admin**: Only one admin account supported
- **Offline Only**: No cloud synchronization
- **Android Only**: No iOS version
- **Single Device**: No multi-device sync
- **Manual Backup**: No automatic database backup

---

## 9. Maintenance and Support

### 9.1 Database Backup

```dart
// Backup database file
Future<void> backupDatabase() async {
  final dbPath = await getDatabasePath();
  final backupPath = '${dbPath}_backup_${DateTime.now().millisecondsSinceEpoch}';
  await File(dbPath).copy(backupPath);
}
```

### 9.2 Common Issues and Solutions

**Issue: Database generation fails**
```bash
# Solution
flutter clean
flutter pub get
flutter packages pub run build_runner build --delete-conflicting-outputs
```

**Issue: Kiosk mode not working**
- Check device permissions
- Verify MDM configuration
- Test on different Android version

**Issue: Provider not updating**
- Ensure provider invalidation after database changes
- Check for circular dependencies
- Verify AsyncValue handling

### 9.3 Future Enhancements

- [ ] Cloud synchronization
- [ ] Multi-device support
- [ ] Barcode scanning for items
- [ ] Email notifications
- [ ] Advanced reporting
- [ ] iOS version
- [ ] Multi-admin support
- [ ] Photo documentation for conditions
- [ ] QR code student identification

---

## 10. Development Team Notes

### 10.1 Code Style Guidelines

- Follow Dart style guide
- Use meaningful variable names
- Document complex business logic
- Keep functions small and focused
- Use const constructors when possible
- Implement proper error handling

### 10.2 Git Commit Guidelines

```
feat: Add item restoration feature
fix: Correct quantity update logic
docs: Update DEVELOPMENT.md
refactor: Simplify borrow service
test: Add unit tests for student registration
```

### 10.3 Code Review Checklist

- [ ] Code follows style guidelines
- [ ] No hardcoded values
- [ ] Proper error handling
- [ ] Database transactions used correctly
- [ ] Providers invalidated after updates
- [ ] No breaking changes to database schema
- [ ] Tests updated/added
- [ ] Documentation updated

---

## Conclusion

This document provides a comprehensive overview of the ToolEase development process, architecture, and implementation details. It serves as a reference for developers, stakeholders, and documentation purposes.

**Project Status**: Production Ready
**Last Updated**: 2025-11-18
**Version**: 1.0.0

For questions or support, refer to the README.md and CLAUDE.md files.

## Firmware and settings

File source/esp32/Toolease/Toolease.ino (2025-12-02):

/**
 * ToolEase RFID Scanner - ESP32 Firmware
 * 
 * Uses EasyMFRC522 library for reading/writing RFID tags
 * Communicates with Flutter app via WiFi WebSocket
 * 
 * Hardware Setup:
 * - ESP32 DevKit
 * - RC522 RFID Module
 * 
 * Pin Layout:
 * MFRC522      ESP32
 * SDA(SS)      GPIO 5
 * SCK          GPIO 18
 * MOSI         GPIO 23
 * MISO         GPIO 19
 * RST          GPIO 21
 * 3.3V         3.3V
 * GND          GND
 */

#include <EasyMFRC522.h>
#include "Rfid_Config.h"
#include "Websocket_Config.h"

// WiFi credentials - ESP32 creates an Access Point
const char* ssid = "ToolEase_RFID";
const char* password = "toolease123";

// Initialize RFID and WebSocket
Rfid_Config rfid(5, 21); // SS_PIN 5, RST_PIN 21 for ESP32
Websocket_Config ws(ssid, password);

// State management
bool scanRequested = false;
bool writeRequested = false;
String writeLabel = "";
String writeData = "";
unsigned long lastScanTime = 0;
const unsigned long SCAN_COOLDOWN = 1000; // 1 second cooldown between scans

void setup() {
  Serial.begin(115200);
  delay(100);
  
  Serial.println("\n\n=================================");
  Serial.println("ToolEase RFID Scanner v3.0 (WiFi)");
  Serial.println("=================================");
  
  // Initialize RFID
  rfid.init();
  Serial.println("[OK] RFID reader initialized");
  
  // Initialize WiFi and WebSocket
  ws.init();
  Serial.println("[OK] WebSocket server started");
  
  Serial.println("=================================");
  Serial.println("System ready. Waiting for WebSocket connection...");
  Serial.println("=================================\n");
}

void loop() {
  // Handle WebSocket communication
  ws.loop();

  // Check for scan request from Flutter app
  if (ws.hasScanRequest()) {
    scanRequested = true;
    ws.clearScanRequest();
    Serial.println("[CMD] Scan request received from app");
  }

  // Check for write request from Flutter app
  if (ws.hasWriteRequest()) {
    String writeCommand = ws.getWriteData();
    Serial.println("[CMD] Write request received: " + writeCommand);
    
    // Parse write command: "label:data"
    int colonIndex = writeCommand.indexOf(':');
    if (colonIndex != -1) {
      writeLabel = writeCommand.substring(0, colonIndex);
      writeData = writeCommand.substring(colonIndex + 1);
      writeRequested = true;
    } else {
      Serial.println("[ERROR] Invalid write command format");
      ws.sendMessage("WRITE_ERROR");
    }
    ws.clearWriteRequest();
  }

  // Handle RFID scanning
  if (scanRequested) {
    handleRFIDScan();
  }

  // Handle RFID writing
  if (writeRequested) {
    handleRFIDWrite();
  }

  // Auto-scan mode (optional - for testing)
  // Uncomment below to enable continuous scanning without app request
  /*
  if (!scanRequested && millis() - lastScanTime > 3000) {
    if (rfid.detectTag()) {
      String uid = rfid.getUID();
      Serial.println("[AUTO] Tag detected: " + uid);
      ws.broadcastUID(uid);
      rfid.unselectTag();
      lastScanTime = millis();
    }
  }
  */

  delay(50); // Small delay to prevent overwhelming the loop
}

/**
 * Handle RFID tag scanning
 * Waits for tag, reads UID, and sends to Flutter app
 */
void handleRFIDScan() {
  unsigned long scanStartTime = millis();
  const unsigned long SCAN_TIMEOUT = 20000; // 20 seconds timeout

  Serial.println("[SCAN] Waiting for RFID tag...");

  while (millis() - scanStartTime < SCAN_TIMEOUT) {
    if (rfid.detectTag()) {
      String uid = rfid.getUID();
      
      if (uid.length() > 0) {
        Serial.println("[SUCCESS] Tag scanned: " + uid);
        ws.broadcastUID(uid); // Send to Flutter app
        rfid.unselectTag();
        scanRequested = false;
        lastScanTime = millis();
        return;
      }
    }
    
    ws.loop(); // Keep WebSocket alive during scan
    delay(100);
  }

  // Timeout reached
  Serial.println("[TIMEOUT] No tag detected within timeout period");
  ws.sendMessage("TIMEOUT");
  scanRequested = false;
}

/**
 * Handle RFID tag writing (optional feature)
 * Waits for tag, writes data, and confirms
 */
void handleRFIDWrite() {
  unsigned long writeStartTime = millis();
  const unsigned long WRITE_TIMEOUT = 15000; // 15 seconds timeout

  Serial.println("[WRITE] Waiting for RFID tag to write...");
  Serial.println("[WRITE] Label: " + writeLabel);
  Serial.println("[WRITE] Data: " + writeData);

  while (millis() - writeStartTime < WRITE_TIMEOUT) {
    if (rfid.detectTag()) {
      Serial.println("[WRITE] Tag detected, writing data...");
      
      int result = rfid.writeFile(writeLabel, writeData);
      
      if (result >= 0) {
        Serial.println("[SUCCESS] Data written successfully");
        ws.sendMessage("WRITE_SUCCESS");
      } else {
        Serial.println("[ERROR] Failed to write data. Error code: " + String(result));
        ws.sendMessage("WRITE_ERROR");
      }
      
      rfid.unselectTag();
      writeRequested = false;
      return;
    }
    
    ws.loop(); // Keep WebSocket alive during write
    delay(100);
  }

  // Timeout reached
  Serial.println("[TIMEOUT] No tag detected for writing");
  ws.sendMessage("WRITE_ERROR");
  writeRequested = false;
}

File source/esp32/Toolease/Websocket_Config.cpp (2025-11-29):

#include "Websocket_Config.h"
#include <vector>

using namespace websockets;

Websocket_Config::Websocket_Config(const char* ssid, const char* password)
    : _ssid(ssid), _password(password), _hasWriteRequest(false) {}

void Websocket_Config::init() {
    WiFi.softAP(_ssid, _password);
    Serial.println("Access Point started");
    Serial.println(WiFi.softAPIP());

    _webSocket.listen(81);
    Serial.println("WebSocket server started on port 81");
}

void Websocket_Config::loop() {
    // Accept new clients
    WebsocketsClient newClient = _webSocket.accept();
    if (newClient.available()) {
        newClient.onMessage([this](WebsocketsClient& client, WebsocketsMessage message) {
            this->onWebSocketMessage(client, message);
        });
        newClient.onEvent([this](WebsocketsClient& client, WebsocketsEvent event, String data) {
            this->onWebSocketEvent(client, event, data);
        });
        _clients.push_back(newClient);
        Serial.println("New WebSocket client connected");
    }

    // Poll existing clients and remove disconnected ones
    for (auto it = _clients.begin(); it != _clients.end(); ) {
        if (it->available()) {
            it->poll();
            ++it;
        } else {
            Serial.println("WebSocket client disconnected");
            it = _clients.erase(it);
        }
    }
}

void Websocket_Config::onWebSocketMessage(WebsocketsClient &client, WebsocketsMessage message) {
    String data = message.data();
    Serial.println("[WebSocket] Message received: " + data);
    // Parse JSON
    if (data.indexOf("\"action\":\"write_tag\"") != -1) {
        int start = data.indexOf("\"data\":\"") + 8;
        int end = data.indexOf("\"", start);
        if (start != -1 && end != -1) {
            _writeData = data.substring(start, end);
            _hasWriteRequest = true;
            Serial.println("Write request received: " + _writeData);
        }
    }
}

void Websocket_Config::onWebSocketEvent(WebsocketsClient &client, WebsocketsEvent event, String data) {
    if (event == WebsocketsEvent::ConnectionClosed) {
        Serial.println("WebSocket connection closed");
    }
}

void Websocket_Config::broadcastUID(String uid) {
    String message = "{\"action\":\"rfid_scan\",\"uid\":\"" + uid + "\"}";
    for (auto& client : _clients) {
        if (client.available()) {
            client.send(message);
        }
    }
    Serial.println("Broadcasted UID: " + uid);
}

bool Websocket_Config::hasWriteRequest() {
    return _hasWriteRequest;
}

String Websocket_Config::getWriteData() {
    return _writeData;
}

void Websocket_Config::clearWriteRequest() {
    _hasWriteRequest = false;
    _writeData = "";
}

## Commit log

2025-11-26 Add Rfid_Config.h: Renamed from Rfid_Reader.h, encapsulates RFID reader functionality with MFRC522. Includes methods for initialization, reading UID, storing last read UID, clearing UID, and writing 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
2025-11-26 Add Rfid_Config.cpp: Implementation of Rfid_Config class. Handles MFRC522 initialization via SPI, reads RFID card UIDs and stores them as hex strings, provides getter and setter for last UID, and imp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
2025-11-26 Add Websocket_Config.cpp: Implementation of Websocket_Config class. Sets up ESP32 as WiFi Access Point, initializes WebSocket server on port 81, handles client connections/disconnections, parses inco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
2025-11-26 Add Toolease.ino: Main Arduino sketch for ESP32-based RFID inventory system. Initializes RFID and WebSocket configurations, runs main loop for reading RFID tags and broadcasting UIDs, handles write r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
2025-11-29 Add .gitignore to ignore STL and G-code files; Update README.md with detailed 3D Models section including Fusion 360 design, Creality Ender V3 SE printing specs with PLA+ filament, 60C bed and 210C n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
2025-11-29 Update README.md to link STL files to Thingiverse (https://www.thingiverse.com/thing:7216344) instead of local files; Remove STL files from project structure since they are not tracked in the reposit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
2025-11-29 Add Tablet Cover to 3D Models section in README.md, including description, Thingiverse link, and print settings; Update project structure to include Toolease_Tablet_Cover.png
2025-11-29 Fix RFID compilation error in ESP32 code
    [Toolease.ino]
2025-11-29 Implement missing Websocket_Config methods
    [Websocket_Config.cpp]
2025-11-29 Update README with comprehensive documentation and fix RFID tag management
    - Completely rewrite README.md with detailed feature coverage
    - Add item names display in manage RFID tags screen
    - Implement automatic item unit creation for existing items
    - Update database service to create units when items are added
    - Fix type imports and method signatures in manage_tags_screen.dart
    - Add WebSocket service and item unit provider
    - Update pubspec.yaml and regenerate database code
    [Toolease.ino]
2025-12-02 docs: add detailed physical assembly, full views, and wiring diagrams to README
    [Wiring.fzz]
2025-12-02 docs: add cable cover and update 3D model descriptions in README
2025-12-02 docs: add Thingiverse link for STL files in README
2025-12-02 docs: add detailed Bill of Materials (BOM) and procurement sources to README
2025-12-02 Add all changes
    [Toolease.f3d]
2025-12-02 Remove tracked .f3d file
    [Toolease.f3d]
2025-12-03 Fix kiosk mode functionality and implement proper settings persistence
    - Add missing settings methods to database_service.dart (getSetting, updateSetting, getAllSettings, isScreenEnabled)
    - Replace stub implementations in settings_provider.dart with actual database-backed providers
    - Fix kiosk mode toggle to properly persist settings and refresh state
    - Kiosk mode now works correctly - toggles persist across app restarts
    - Tested successfully on Android device - kiosk mode enables/disables properly
    Technical details:
    - Settings are now stored in SQLite database using Drift ORM
    - Kiosk mode provider reads from database on app initialization
    - Settings notifier properly updates and persists a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
